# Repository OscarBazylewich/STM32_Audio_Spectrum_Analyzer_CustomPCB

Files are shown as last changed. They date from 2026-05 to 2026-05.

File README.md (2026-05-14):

# STM32_Audio_Spectrum_Analyzer_CustomPCB
This project utilizes an STM32L4Q5CGT micrcontroller to reduce pcb size with the added benefit of having similar functionality to most of ST's STM32 Performance line MCUs that are relevant to this project. 

KiCAD 9.0 3D Viewer which includes all 3D models
Front
STMASAFront
Back
STMASABack

KiCAD 10.0 3D Viewer which doesnt include all 3D models but added extra GND pour on layers 1 and 4
Front

Back


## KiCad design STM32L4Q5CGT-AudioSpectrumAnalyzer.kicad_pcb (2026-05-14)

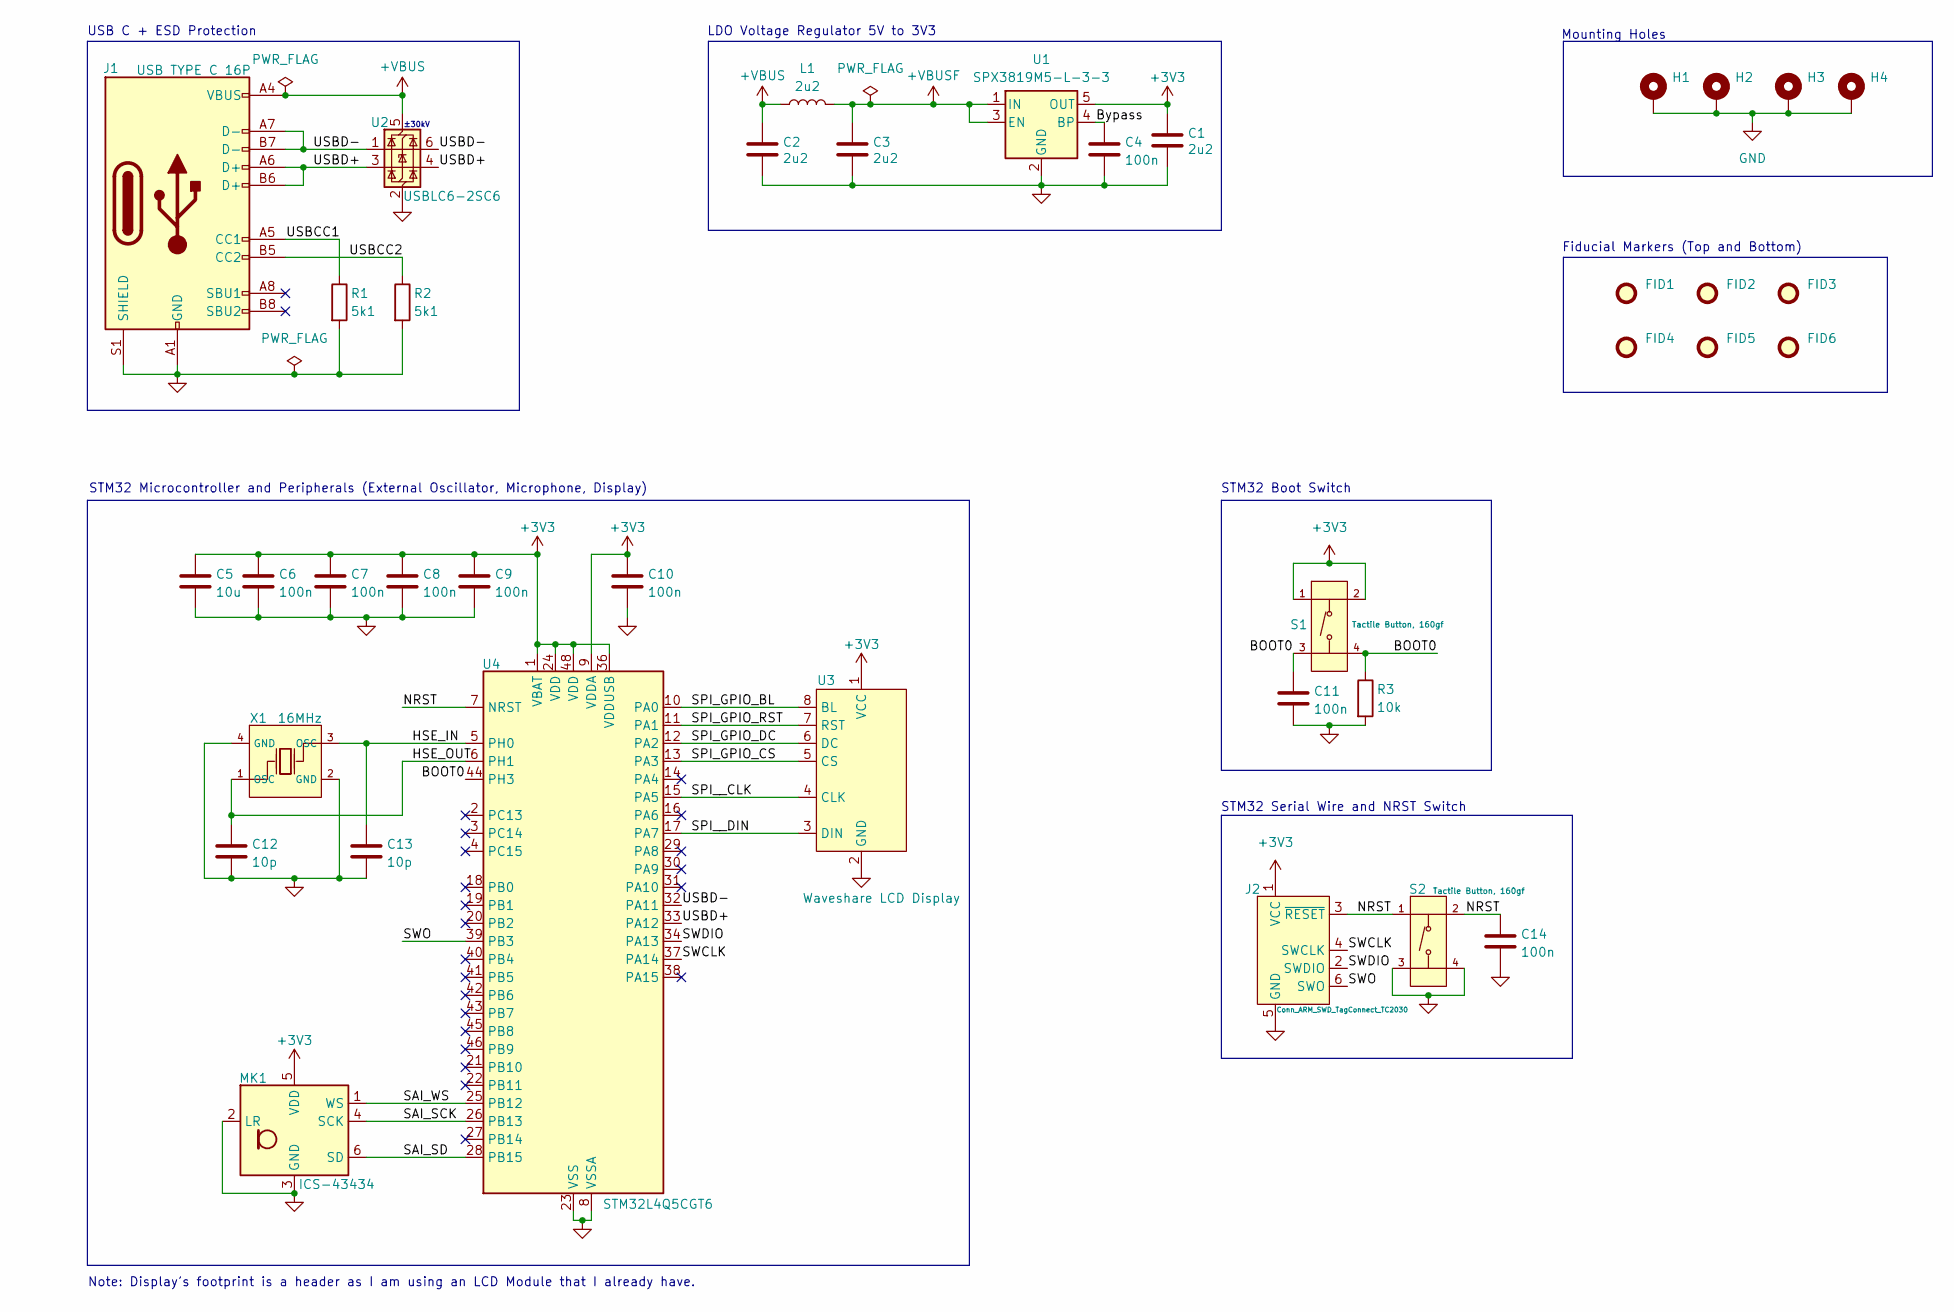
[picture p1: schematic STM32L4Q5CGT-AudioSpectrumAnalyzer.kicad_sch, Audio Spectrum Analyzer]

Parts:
C1: 2u2; C_CASE-A-3216-18(mm); Manufacturer Part Number T491A225K035AT; LCSC C122264
C2, C3: 2u2; C_0603_1608Metric_Pad1.08x0.95mm_HandSolder; Manufacturer Part Number CL31B225KBHNNNE; LCSC C23630
C4, C6, C7, C8, C9, C10, C11, C14: 100n; C_0402_1005Metric_Pad0.74x0.62mm_HandSolder; Manufacturer Part Number CL05B104KO5NNNC; LCSC C1525
C5: 10u; C_0603_1608Metric_Pad1.08x0.95mm_HandSolder; Manufacturer Part Number CL10A106KP8NNNC; LCSC C19702
C12, C13: 10p; C_0603_1608Metric_Pad1.08x0.95mm_HandSolder; Manufacturer Part Number CL10C100JB8NNNC; LCSC C1634
FID1, FID2, FID3, FID4, FID5, FID6: Fiducial; Fiducial_1mm_Mask2mm
H1, H2, H3, H4: MountingHole_Pad; MountingHole_3.2mm_M3_Pad
J1: USB TYPE C 16P; USB_C_Receptacle_GCT_USB4105-xx-A_16P_TopMnt_Horizontal; Manufacturer Part Number KH-TYPE-C-16P; LCSC C709357
J2: Conn_ARM_SWD_TagConnect_TC2030; Tag-Connect_TC2030-IDC-FP_2x03_P1.27mm_Vertical
L1: 2u2; L_1206; Manufacturer Part Number LQM31PN2R2M00L; LCSC C171763
MK1: ICS-43434; InvenSense_ICS-43434-6_3.5x2.65mm; Manufacturer Part Number ICS-43434; LCSC C5656610
R1, R2: 5k1; R_0402_1005Metric_Pad0.72x0.64mm_HandSolder; Manufacturer Part Number 0402WGF5101TCE; LCSC C25905
R3: 10k; R_0402_1005Metric_Pad0.72x0.64mm_HandSolder; Manufacturer Part Number 0402WGF1002TCE; LCSC C25744
S1, S2: Tactile Button, 160gf; SW-SMD_4P-L5.1-W5.1-P3.70-LS6.5-TL-2; Manufacturer Part Number TS-1187A-B-A-B; LCSC C318884
U1: SPX3819M5-L-3-3; SOT-23-5; Manufacturer Part Number SPX3819M5-L-3-3/TR; LCSC C9055
U2: USBLC6-2SC6; SOT-23-6; Manufacturer Part Number USBLC6-2SC6; LCSC C2687116
U3: Waveshare LCD Display; PinHeader_1x08_P2.54mm_Vertical; Manufacturer Part Number 2.54-1*8; LCSC C5156616
U4: STM32L4Q5CGT6; LQFP-48_7x7mm_P0.5mm; Manufacturer Part Number STM32L4Q5CGT6; LCSC C1236662
X1: 16MHz; OSC-SMD_4P-L3.2-W2.5-BL; Manufacturer Part Number X322516MLB4SI; LCSC C13738

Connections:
+3V3: C1.1, C5.1, C6.1, C7.1, C8.1, C9.1, C10.1, J2.1 (VCC), MK1.5 (VDD), S1.1 (A), S1.2 (B), U1.5 (OUT), U3.1 (VCC), U4.1 (VBAT), U4.9 (VDDA), U4.24 (VDD), U4.36 (VDDUSB), U4.48 (VDD)
+VBUS: C2.1, J1.A4 (VBUS), J1.A9 (VBUS), J1.B4 (VBUS), J1.B9 (VBUS), L1.1, U2.5 (VBUS)
+VBUSF: C3.1, L1.2, U1.1 (IN), U1.3 (EN)
/BOOT0: C11.1, R3.1, S1.3 (C), S1.4 (D), U4.44 (PH3)
/Bypass: C4.1, U1.4 (BP)
/HSE_IN: C13.1, U4.5 (PH0), X1.3 (OSC)
/HSE_OUT: C12.1, U4.6 (PH1), X1.1 (OSC)
/NRST: C14.1, J2.3 (~RESET), S2.1 (A), S2.2 (B), U4.7 (NRST)
/SAI_SCK: MK1.4 (SCK), U4.26 (PB13)
/SAI_SD: MK1.6 (SD), U4.28 (PB15)
/SAI_WS: MK1.1 (WS), U4.25 (PB12)
/SPI_GPIO_BL: U3.8 (BL), U4.10 (PA0)
/SPI_GPIO_CS: U3.5 (CS), U4.13 (PA3)
/SPI_GPIO_DC: U3.6 (DC), U4.12 (PA2)
/SPI_GPIO_RST: U3.7 (RST), U4.11 (PA1)
/SPI__CLK: U3.4 (CLK), U4.15 (PA5)
/SPI__DIN: U3.3 (DIN), U4.17 (PA7)
/SWCLK: J2.4 (SWCLK), U4.37 (PA14)
/SWDIO: J2.2 (SWDIO), U4.34 (PA13)
/SWO: J2.6 (SWO), U4.39 (PB3)
/USBCC1: J1.A5 (CC1), R1.1
/USBCC2: J1.B5 (CC2), R2.1
/USBD+: J1.A6 (D+), J1.B6 (D+), U2.3 (I/O2), U2.4 (I/O2), U4.33 (PA12)
/USBD-: J1.A7 (D-), J1.B7 (D-), U2.1 (I/O1), U2.6 (I/O1), U4.32 (PA11)
GND: C1.2, C2.2, C3.2, C4.2, C5.2, C6.2, C7.2, C8.2, C9.2, C10.2, C11.2, C12.2, C13.2, C14.2, H1.1 (1_1), H2.1 (1_1), H3.1 (1_1), H4.1 (1_1), J1.A1 (GND), J1.A12 (GND), J1.B1 (GND), J1.B12 (GND), J1.S1 (SHIELD), J2.5 (GND), MK1.2 (LR), MK1.3 (GND), R1.2, R2.2, R3.2, S2.3 (C), S2.4 (D), U1.2 (GND), U2.2 (GND), U3.2 (GND), U4.8 (VSSA), U4.23 (VSS), U4.35 (VSS), U4.47 (VSS), X1.2 (GND), X1.4 (GND)

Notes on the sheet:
LDO Voltage Regulator 5V to 3V3
STM32 Boot Switch
STM32 Microcontroller and Peripherals (External Oscillator, Microphone, Display)
STM32 Serial Wire and NRST Switch
Mounting Holes
±30kV
Note: Display's footprint is a header as I am using an LCD Module that I already have.
Fiducial Markers (Top and Bottom)
USB C + ESD Protection

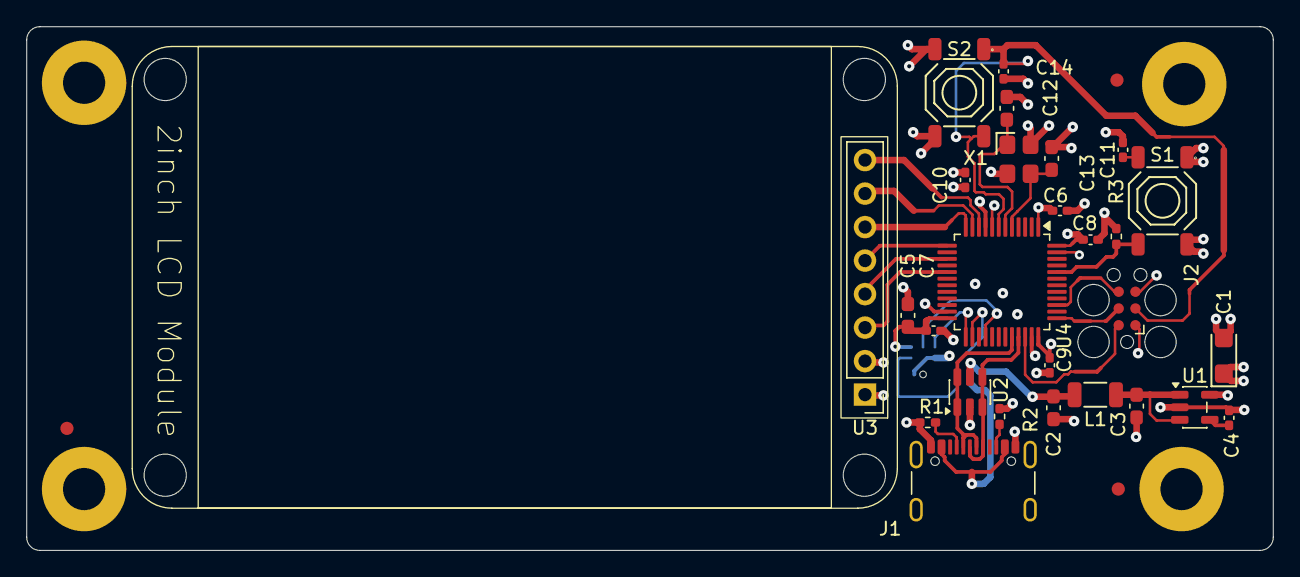
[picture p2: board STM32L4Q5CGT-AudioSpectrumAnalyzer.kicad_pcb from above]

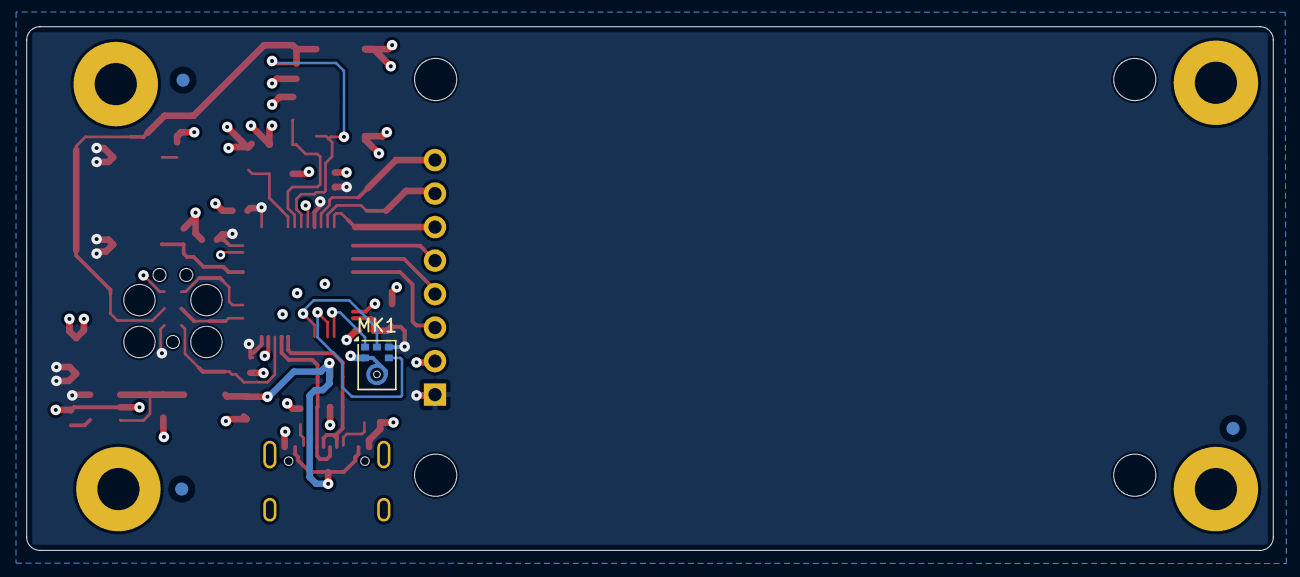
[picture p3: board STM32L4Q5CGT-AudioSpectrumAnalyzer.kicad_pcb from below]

Board: 4 copper layers, 94.5 x 39.7 mm, 38 parts (4 on the bottom side), 25 nets.

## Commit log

2026-11-03 Rewrite README and show KiCad files in GitHub stats
    Add an overview, status, feature list, block diagram, BOM with MPNs,
    board specs, pin assignments, connector pinouts, circuit notes, KiCad
    and fabrication steps, a render gallery and a link to the Nucleo
    prototype. Add .gitattributes so GitHub counts KiCad files in language
    stats.
2026-11-03 Shorten README and match my writing style
    Cut the README to about half its length, reuse my original wording
    where it is still accurate, and keep the verified facts and images.
